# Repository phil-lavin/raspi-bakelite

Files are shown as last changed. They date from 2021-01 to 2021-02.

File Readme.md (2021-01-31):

Raspberry Pi Bakelite Phone VoIP Interface Board
================================================

Intro
-----

This repo contains the various bits of code that go to make up the VoIP conversion of a 1950s Bakelite phone using a Raspberry Pi.

The interface between the Raspberry Pi and the phone has been done by means of a custom designed [Pi Hat](https://github.com/raspberrypi/hats). 

Component Directories
---------------------

Below is a list of the components of this project. Each has its own Readme.md.

* eeprom: Contains all of the code held on the hat's 64Kbit EEPROM chip
* hat: Contains schematics, board designs and Gerber files for the custom designed Pi Hat
* ringer: Contains details of the original ringer bell of the Bakelite phone and how it's powered in the VoIP conversion

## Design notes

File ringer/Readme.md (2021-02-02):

Ringer
======

The Bakelite phone contains a pretty distinctive sounding ringer. It was important for this project
to preserve that sound. The ringer comprises of two solenoid coils, connected to a hammer. The AC
current causes the hammer to move back and forth between the coils, banging on the bells.

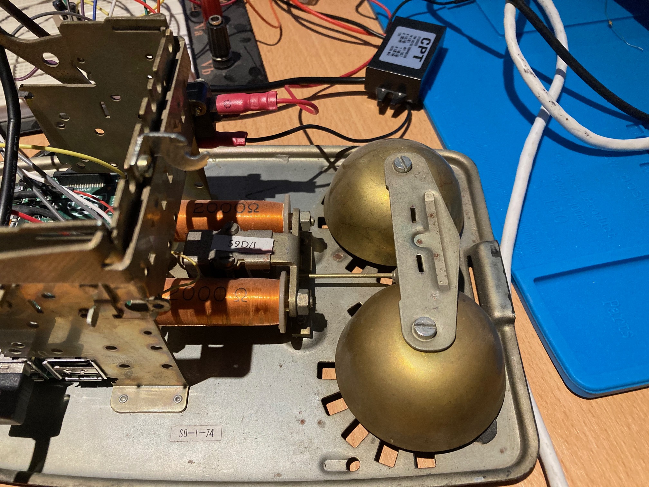
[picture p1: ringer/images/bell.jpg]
Ringer Bell

*Ringer Bells*

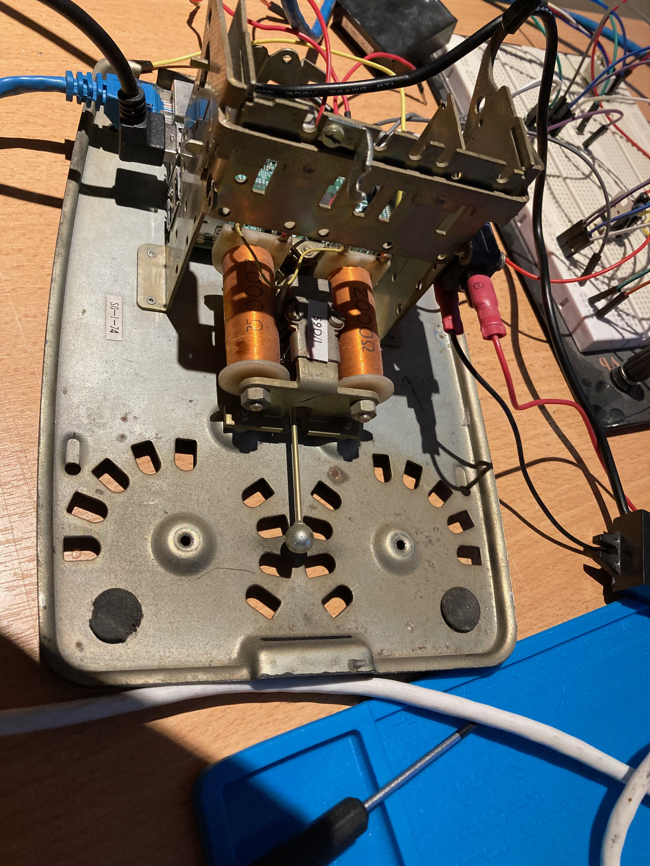
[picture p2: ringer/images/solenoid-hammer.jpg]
Solenoid Hammer

*Solenoid and Hammer with Bells Removed*

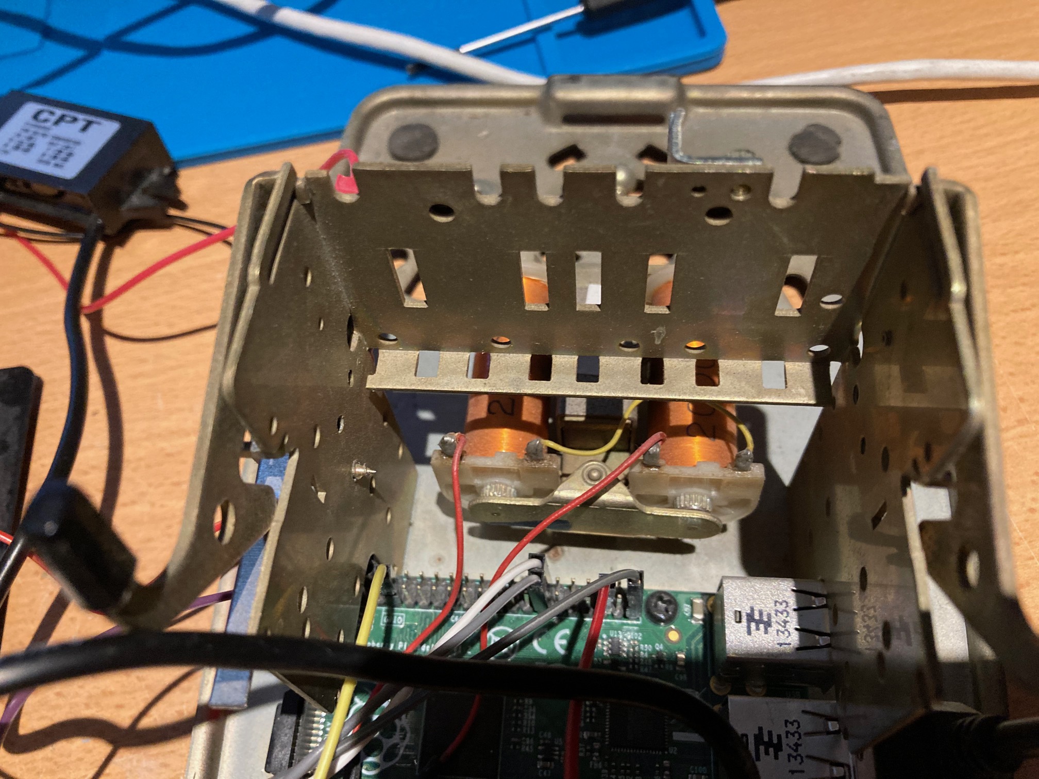
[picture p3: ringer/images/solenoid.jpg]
Solenoid

*Solenoid*

## Making it Ring

British PSTN ringing voltage is circa 75V AC at 25Hz. I decided to use the `PCR-SIN03V12F20-C` ring generator. 
This is a pre-packaged generator that converts 12V DC to 70V AC at 20Hz. Not exactly right, but who's going 
to notice?

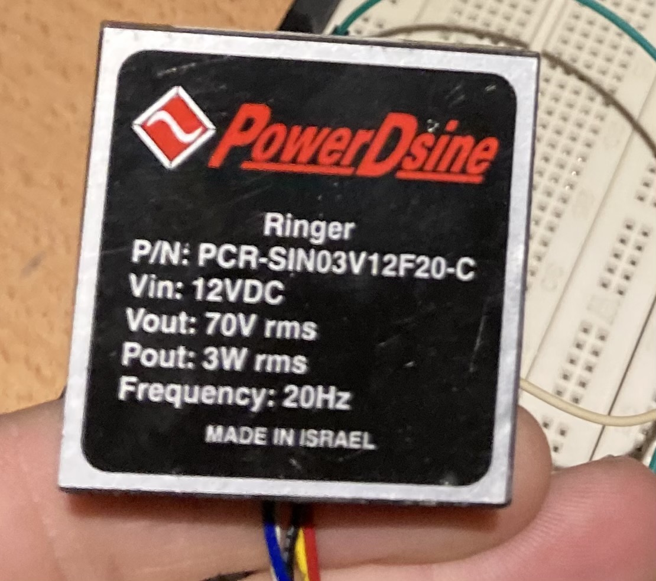
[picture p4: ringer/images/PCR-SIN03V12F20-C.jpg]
PCR-SIN03V12F20-C Ring Generator

*PCR-SIN03V12F20-C Ring Generator*

The `PCR-SIN03V12F20-C` has 6 pins (only 5 are connected):

* Pin 1: Connection to Solenoid
* Pin 2: Connection to Solenoid
* Pin 3: 12V DC
* Pin 4: GND
* Pin 5: 
* Pin 6: Inhibit

All pins should be pretty self explanatory, except Inhibit. When 5V (relative to GND) is applied to this pin 
it puts the device into low power mode and stops it outputting current to the solenoid.

When connected up to a scope, this is what the wave looks like:

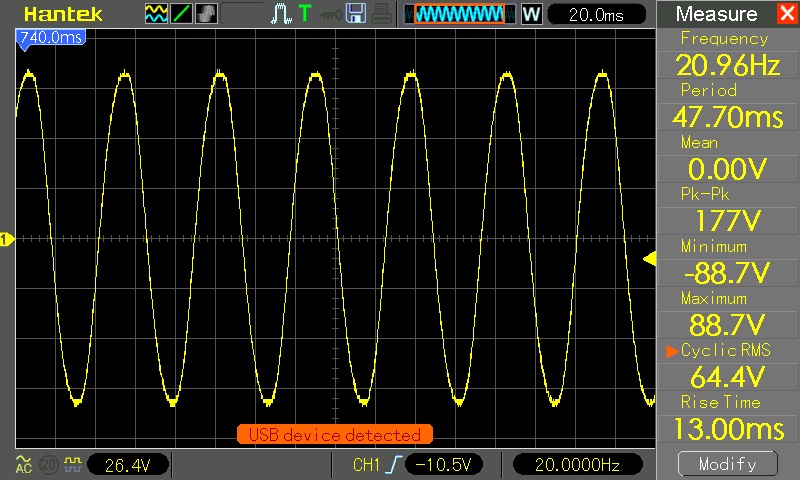
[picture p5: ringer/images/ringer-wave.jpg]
PCR-SIN03V12F20-C Wave


You can see that the wave is around 63V RMS at 20Hz. When connected to the solenoid, it makes a fantastic 
original sound.

## Circuit

The circuit to control the `PCR-SIN03V12F20-C` is pretty simple:

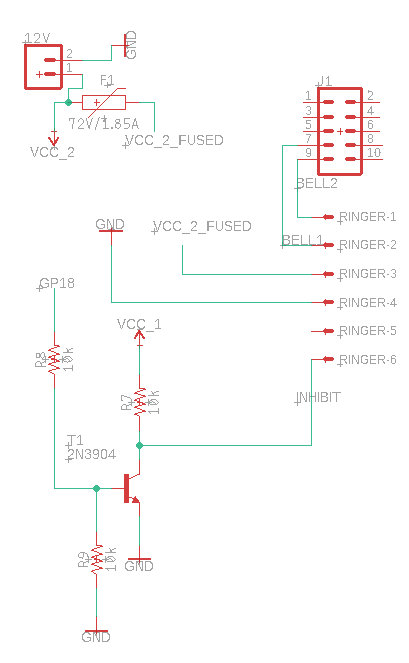
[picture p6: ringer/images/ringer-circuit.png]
PCR-SIN03V12F20-C Control Circuit


The `PCR-SIN03V12F20-C` ringer module takes a 12V power and GND input (pins 3 and 4) and it outputs to the Bakelite's original ringer (pins 1 and 2). Pin 6 of the ringer module is the `INHIBIT` pin. This 
pin takes a 5V logic input and when it's held high, the ringer stops outputting. When the pin is held low, the ringer outputs (and thus the bell rings). Because the Pi 
doesn't have any 5V GPIOs, this is fed via a transistor and simple inverter circuit. Under normal operation, the pin is tied directly to the 5V line via a 10K resistor. 
When the Pi's GPIO output goes high, this "opens up" the transistor and pulls the `INHIBIT` pin to GND. This makes the bell ring.

In essence, when the Pi's GPIO is high, the bell rings. When it's low, it doesn't.

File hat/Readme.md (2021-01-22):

Raspberry Pi Bakelite Phone VoIP Interface Board - Hat Designs
=========================================================

## Intro

The Bakelite Interface Board is designed to the functional and [mechanical specifications](https://github.com/raspberrypi/hats/blob/master/hat-board-mechanical.pdf) of a [Pi Hats](https://github.com/raspberrypi/hats).

This directory contains the Eagle cam files (schematic, board and gerbers... and image exports thereof) for the board.

## Schematic

Here is the Eagle schematic for the hat:

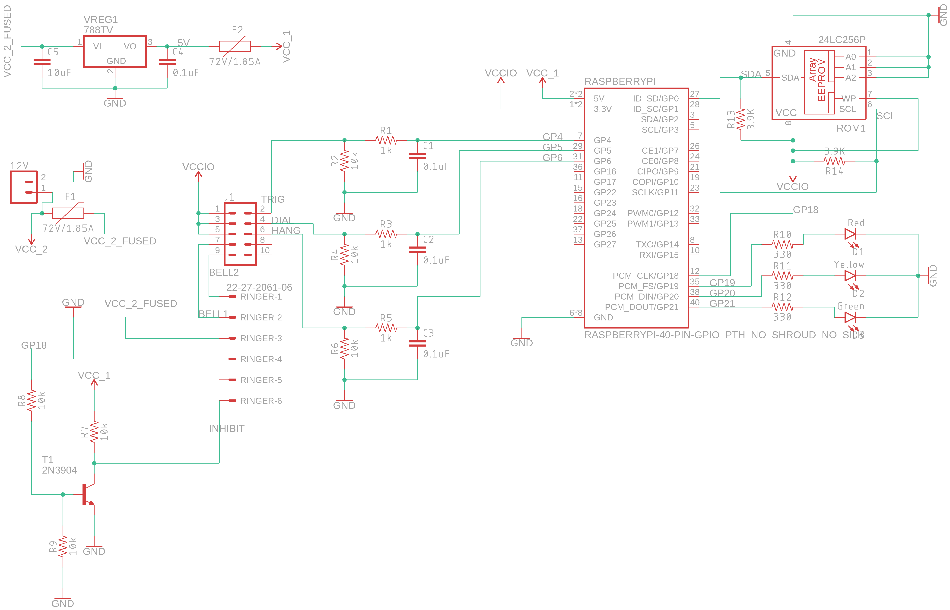
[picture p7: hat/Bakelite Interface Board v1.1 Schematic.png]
Eagle Schematic


The actual Eagle schematic file is also in this directory (the `.sch` file).

The schematic is focussed around the Raspberry Pi's 40 pin connector. This is just a 40 pin female connector, correctly positioned, on the Hat board such that 
the Hat sits directly on top of the Pi.

The schematic looks complicated but it's actually just a bunch of simple circuits all stitched together. These are:

### 12v Input (Middle Left of Schematic)

This is just a 2 pin screw header which takes an external 12V input (`VCC_2`) and puts it through a 2A resettable Polyfuse to create `VCC_2_FUSED`.

### 5v Power (Top Left of Schematic)

This takes the fused 12V output (`VCC_2_FUSED`) and passes it through a 5V regulator and a 2A resettable Polyfuse. This is then fed into the 5V pin of the Pi, 
thus providing power to the Pi from the 12V input.

The schematic notes that the regulator is a `788TV` (5V/2A Linear Regulator) but I will actually use the `K7805-2000` which is a pin compatible switching regulator.
It's more expensive but it's more efficient and runs a lot less hot, such that it doesn't need a heatsink.

The capacitors are just to ensure a smooth power feed is received.

### Ringer Control (Bottom Left of Schematic)

I am using a pre-packaged ring generator which is external from the board. This is a PowerDsine `PCR-SIN03V12F20-C`. It has a 6 pin Molex `2502` connector. This connector 
connects to the 6 pin connector on the board (labelled `RINGER-1` to `RINGER-6`).

The board also has a standard 10 pin header on it. The Bakelite's original ringer connects to this (pins 7 and 9).

The `PCR-SIN03V12F20-C` ringer module takes a 12V power and GND input (pins 3 and 4) and it outputs to the Bakelite's original ringer (pins 1 and 2). Pin 6 of the ringer module is the `INHIBIT` pin. This 
pin takes a 5V logic input and when it's held high, the ringer stops outputting. When the pin is held low, the ringer outputs (and thus the bell rings). Because the Pi 
doesn't have any 5V GPIOs, this is fed via a transistor and simple inverter circuit. Under normal operation, the pin is tied directly to the 5V line via a 10K resistor. 
When the Pi's GPIO output goes high, this "opens up" the transistor and pulls the `INHIBIT` pin to GND. This makes the bell ring.

In essence, when the Pi's GPIO is high, the bell rings. When it's low, it doesn't.

### "Switch" Inputs (Centre of Schematic)

The Bakelite phone has 3 switch-like inputs which we are interested in. All of these start in the on state. 

Two of the switch-like inputs are from the rotary dialler. One of them (named `TRIG` in the schematic) turns off when you start dialling and it turns back on when you stop dialling.
The next (named `DIAL`) in the schematic turns off and on again based on the number you dialled. This generates pulses - so if you dialled 5, you'd get 5 pulses.

The other switch-like input is not part of the original phone. Rather, it is a Long Lever Microswitch which has been attached to the phone just below the cradle that holds the handset.
When the handset is down, this switch is pressed (i.e. on). When the handset is lifted up, the switch turns off. This is connected to the `HANG` input on the schematic.

Each of these switches are connected to a GPIO pin on the Pi through a simple pulldown circuit with an added capacitor for debouncing the switch input. The GPIO pins are normally pulled 
to GND, until the switch is turned on when they are pulled to 3.3V.

### EEPROM Circuit (Top Right of Schematic)

It is a requirement of [Pi Hats](https://github.com/raspberrypi/hats) to have an EEPROM chip at least 32Kb in size connected to the ID (`ID_SC` and `ID_SD`) pins of the Pi.

The EEPROM chip should contain a number of components, in a [defined format](https://github.com/raspberrypi/hats/blob/master/eeprom-format.md), which describe the Hat, its GPIO usage and its Linux device tree. You can also include custom data.

This is much better documented in the eeprom folder of this repository.

### LEDs (Bottom Right of Schematic)

The board contains 3 LEDs, each connected via a resistor, to the Pi's GPIO pins. These can be used by the userland code to provide some sort of status and diagnostic output.

## Gerbers

The Gerber CAM files which have been built to the Design Rules of [Elecrow](https://www.elecrow.com/pcb-manufacturing.html) are in the gerbers directory.

There is a very small cutout at the edge of the board above pin 6 of the GPIO connector. This is just because of the way the Pi is positioned in the Bakelite phone, the Hat needs 
some provision for a bit of metalwork which exists in that space.

This is what a rendering of the top and bottom of the board looks like:

### Top

Top of Board

### Bottom

Bottom of Board

## Board

Here is the Eagle board for the hat:

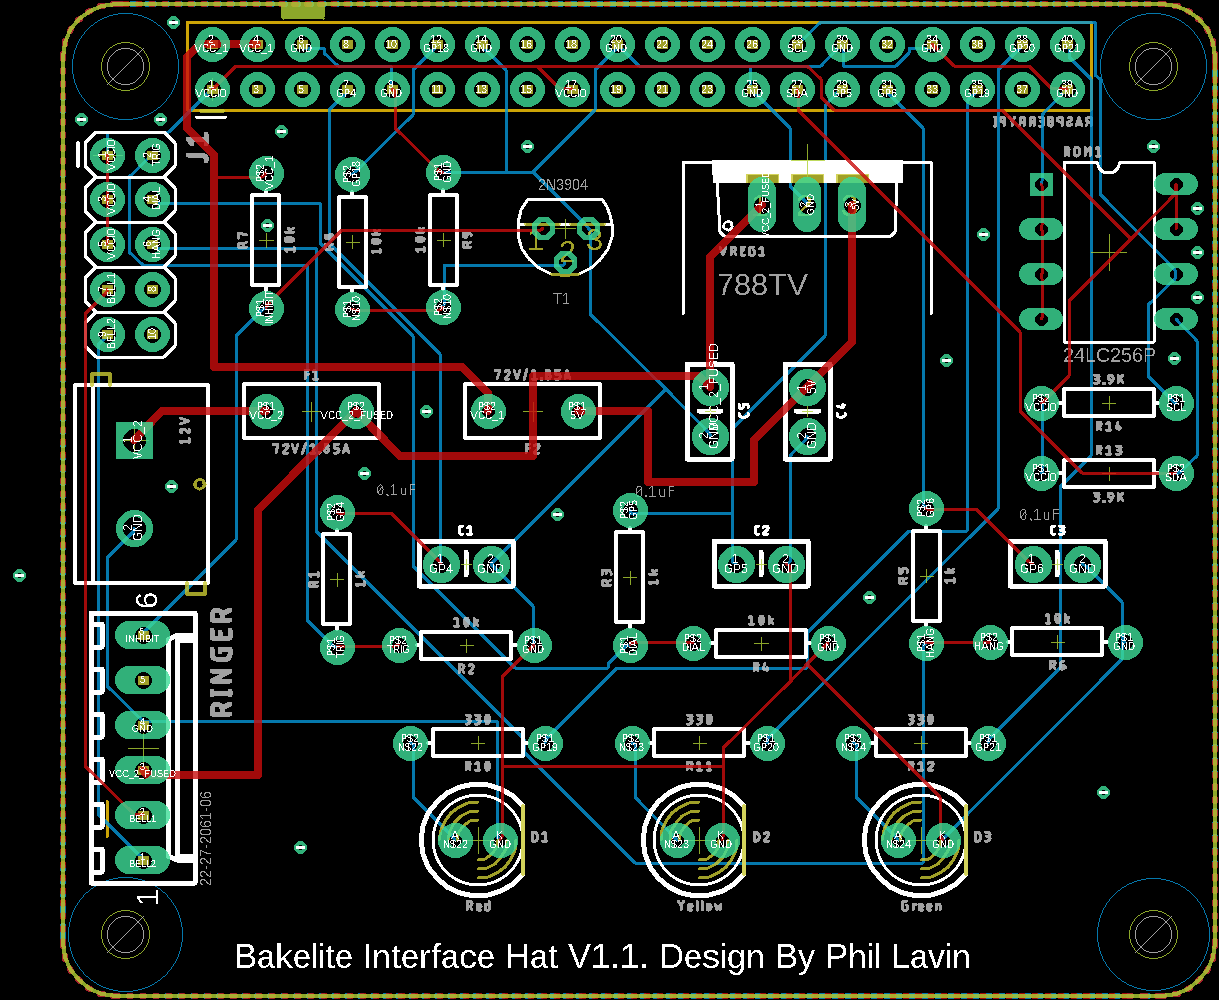
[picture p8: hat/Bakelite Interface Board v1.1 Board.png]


The actual Eagle board file is also in this directory (the `.brd` file).

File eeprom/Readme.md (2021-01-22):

Raspberry Pi Bakelite Phone VoIP Interface Board - EEPROM
=========================================================

## Intro

It is a requirement of [Pi Hats](https://github.com/raspberrypi/hats) to have an EEPROM chip at least 32Kb in size connected to the ID (`ID_SC` and `ID_SD`) pins of the Pi.

The EEPROM chip should contain a number of components, in a [defined format](https://github.com/raspberrypi/hats/blob/master/eeprom-format.md), which describe the Hat, its GPIO usage and its Linux device tree. You can also include custom data.

## Schematic

The EEPROM chip has a few pins:

* SDA/SCL: These are the I2C data lines - they connect to the matching pins on the Pi. They also need to be pulled up, via 3.9k resistors, to the 3.3V VCC
* VCC: 3.3V power input
* GND: Ground connection
* A0, A1, A2: These are the pins to set the I2C address of the EEPROM. They make up a 3 bit address, giving 8 possible addresses. Tying all 3 pins to GND makes the address 0x50, which is what the Pi Hat specification requires
* WP: This is the Write Protect pin. It should be tied to 3.3V if you want to prevent writing to the EEPROM. For the purpose of testing/programming the EEPROM, tie this to GND or leave it floating

Here is the Eagle schematic for this part of the Hat. VCCIO is the 3.3V line from the Pi.

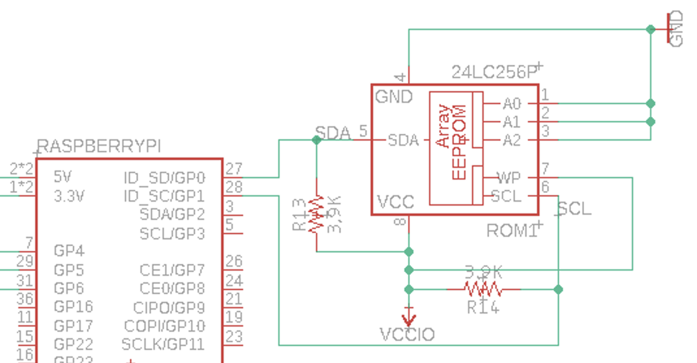
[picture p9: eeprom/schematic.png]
EEPROM Schematic
 

## Files

Below is a list of the files in this directory and a description of them:

* custom.txt: The custom data that gets flashed to the end of the EEPROM. This can be read, with some effort, by your applications
* dtc: Latest (at time of writing) version of the [Device Tree Compiler Toolchain](https://github.com/dgibson/dtc) as the version shipped on the Pi is buggy and segfaults when examining the Pi. This was compiled on a Pi Model B+ running Buster
* eeprom.py: A small bit of Python example code, demonstrating traversing the EEPROM's structure and pulling out the custom data written to the end of it
* eeprom_settings.txt: Settings file which is used to construct the main parts of the EEPROM's data
* flasheep.sh: Wrapper script around other tools to flash the EEPROM
* hats/: Git submodule of [Pi Hats](https://github.com/raspberrypi/hats) which contains the tools to build and flash the EEPROM data
* raspi-bakelite.dts: Device Tree definition file for the hat (described in much more depth below!)
* schematic.png: The schematic of the circuit which connects the EEPROM to the Pi

## Flashing the EEPROM

The EEPROM running on this Hat is a `24LC64` 64Kbit chip. The Pi Model B+ has 2 I2C busses, numbered 0 and 1. Bus 0 is the ID pins (27 and 28) and bus 1 is the `SDA`/`SCL` pins (3 and 5).

The Hat specification states that the I2C address of the EEPROM must be 0x50.

The process of flashing the EEPROM is:

* Compile the raspi-bakelie.dts file using dtc
* Build the EEPROM data image from the settings file, device tree and custom data files
* Flatten the EEPROM by writing 32Kbit of 0s to it (to save time as the actual EEPROM data is < 32Kbit)
* Write the data image we built to the chip

Flashing is done using the flasheep.sh wrapper script:

```
root@roto-voip:~/raspi-bakelite/eeprom# ./flasheep.sh 
raspi-bakelite.dts:63.24-67.19: Warning (unit_address_vs_reg): /fragment@2/__overlay__/trig/trig@4: node has a unit name, but no reg or ranges property
raspi-bakelite.dts:77.24-81.19: Warning (unit_address_vs_reg): /fragment@2/__overlay__/dial/dial@5: node has a unit name, but no reg or ranges property
raspi-bakelite.dts:91.24-95.19: Warning (unit_address_vs_reg): /fragment@2/__overlay__/hang/hang@6: node has a unit name, but no reg or ranges property
raspi-bakelite.dts:55.24-68.15: Warning (avoid_unnecessary_addr_size): /fragment@2/__overlay__/trig: unnecessary #address-cells/#size-cells without "ranges" or child "reg" property
raspi-bakelite.dts:69.24-82.15: Warning (avoid_unnecessary_addr_size): /fragment@2/__overlay__/dial: unnecessary #address-cells/#size-cells without "ranges" or child "reg" property
raspi-bakelite.dts:83.24-96.15: Warning (avoid_unnecessary_addr_size): /fragment@2/__overlay__/hang: unnecessary #address-cells/#size-cells without "ranges" or child "reg" property
Opening file eeprom_settings.txt for read
Done reading
Opening DT file raspi-bakelite.dtb for read
Adding 2819 bytes of DT data
Opening custom data file custom.txt for read
Adding 53 bytes of custom data
Writing out...
Writing out DT...
Done.
This will attempt to talk to an eeprom at i2c address 0x50 on bus 0. Make sure there is an eeprom at this address.
This script comes with ABSOLUTELY no warranty. Continue only if you know what you are doing.
Writing...
4096 bytes (4.1 kB, 4.0 KiB) copied, 22 s, 0.2 kB/s
8+0 records in
8+0 records out
4096 bytes (4.1 kB, 4.0 KiB) copied, 22.4986 s, 0.2 kB/s
Closing EEPROM Device.
Done.
This will attempt to talk to an eeprom at i2c address 0x50 on bus 0. Make sure there is an eeprom at this address.
This script comes with ABSOLUTELY no warranty. Continue only if you know what you are doing.
Writing...
2560 bytes (2.6 kB, 2.5 KiB) copied, 14 s, 0.2 kB/s
5+1 records in
5+1 records out
3010 bytes (3.0 kB, 2.9 KiB) copied, 16.5093 s, 0.2 kB/s
Closing EEPROM Device.
Done.
```

## EEPROM Settings

The eeprom_settings.txt file is pretty self explanatory, if you look at it. It defines the name and vendor of the board, that the board provides at least 2A of power to the Pi and it sets ip the 7 GPIO pins used by the Pi.

The custom data in this settings file appears to be limited to 3 bytes. Instead, you should use the custom.txt file to add custom data to the EEPROM which is only limited by the size of the ROM.

You can ensure the GPIO settings have applied with `raspi-gpio get`:

```
root@roto-voip:~/raspi-bakelite# raspi-gpio get | grep 'GPIO [456]:\|GPIO 1[89]\|GPIO 2[01]'
GPIO 4: level=0 fsel=0 func=INPUT
GPIO 5: level=0 fsel=0 func=INPUT
GPIO 6: level=0 fsel=0 func=INPUT
GPIO 18: level=0 fsel=1 func=OUTPUT
GPIO 19: level=0 fsel=1 func=OUTPUT
GPIO 20: level=0 fsel=1 func=OUTPUT
GPIO 21: level=1 fsel=1 func=OUTPUT
```

## EEPROM Custom Data

The custom data can be read off the EEPROM, with some effort, by understanding the [defined format](https://github.com/raspberrypi/hats/blob/master/eeprom-format.md) of the data.

The eeprom.py script in this directory gives a basic example of traversing the data and printing out any Atoms of type 0x0004 (manufacturer custom data).

```
root@roto-voip:~/raspi-bakelite/eeprom# python eeprom.py 
We have 4 atoms
Analysing atom 0
Type is 1
Length is 58
New offset is 78
Analysing atom 1
Type is 2
Length is 32
New offset is 118
Analysing atom 2
Type is 3
Length is 2821
New offset is 2947
Analysing atom 3
Type is 4
Length is 55
Custom data at atom 3: trig=4;dial=5;hang=6;ring=18;led1=19;led2=20;led3=21
```

## Device Tree

This is where things get complicated, and very poorly documented :/

A few useful references:

* https://mjoldfield.com/atelier/2017/03/rpi-devicetree.html
* https://developer.aliyun.com/mirror/npm/package/gpio-button/v/0.1.0
* https://github.com/torvalds/linux/blob/v4.19/include/uapi/linux/input-event-codes.h#L341
* https://www.kernel.org/doc/Documentation/devicetree/bindings/input/gpio-keys.txt
* https://learn.sparkfun.com/tutorials/reading-and-writing-serial-eeproms/all
* https://www.raspberrypi.org/documentation/configuration/device-tree.md

The raspi-bakelite.dts file defines the changes to the Linux Device Tree that should be made when the Pi boots.

It defines a few things:

### 3x LEDs

This maps the GPIO pins used by the LEDs on the Hat to /sys/class/leds/. This is useful because the userland code can now address named LEDs without having to know the pin numbers.

Turning on/off the LEDs is a simple as writing 1 or 0 to the brightness file handle. E.g:

```
echo 1 > /sys/class/leds/green/brightness
```

This turns on the green LED.

### Ringer

### 3x "Button" Inputs

These are the 3 physical switch inputs from the phone (dialing triggered, dialling and hang up). These are mapped to devices in /dev/input/by-path/ and also key presses 
on what is, effectively, a keyboard. Again, this is useful because we can respond to these named events without knowing the pin numbers.

You can use the evtest Linux tool to monitor the devices and report updates:

```
root@roto-voip:~/raspi-bakelite# evtest /dev/input/by-path/platform-soc\:trig-event 
Input driver version is 1.0.1
Input device ID: bus 0x19 vendor 0x1 product 0x1 version 0x100
Input device name: "soc:trig"
Supported events:
  Event type 0 (EV_SYN)
  Event type 1 (EV_KEY)
    Event code 260 (BTN_4)
Properties:
Testing ... (interrupt to exit)
Event: time 1611266120.098545, type 1 (EV_KEY), code 260 (BTN_4), value 1
Event: time 1611266120.098545, -------------- SYN_REPORT ------------
Event: time 1611266121.438556, type 1 (EV_KEY), code 260 (BTN_4), value 0
Event: time 1611266121.438556, -------------- SYN_REPORT ------------
```

### Ringer Output

This is a GPIO output which, via a transistor and basic 5v inverter, drives the INHIBIT pin on the ring generator. When this pin is HIGH, the phone rings, when it is LOW the phone stops 

The ringer output pin is mapped as an LED. There doesn't seem to be a more sensible output driver in Linux, so this'll have to do. It doesn't really matter - we only need a way to
turn it on and off on demand.

```
echo 1 > /sys/class/leds/ringer/brightness
```

This turns the ringer on.

## Testing

You can see the device tree and hat config as it has been translated to the file system with a few different commands:

```
root@roto-voip:~# ls /sys/class/leds/
green  led0  led1  orange  red	ringer

root@roto-voip:~/raspi-bakelite/eeprom# ls /dev/input/by-path/
platform-20980000.usb-usb-0:1.2:1.3-event  platform-soc:dial-event  platform-soc:hang-event  platform-soc:trig-event

root@roto-voip:~/raspi-bakelite/eeprom# grep -a '' /proc/device-tree/hat/*
/proc/device-tree/hat/custom_0:trig=4;dial=5;hang=6;ring=18;led1=19;led2=20;led3=21
/proc/device-tree/hat/name:hat
/proc/device-tree/hat/product:Bakelite Interface Board
/proc/device-tree/hat/product_id:0x0001
/proc/device-tree/hat/product_ver:0x0002
/proc/device-tree/hat/uuid:79f507e0-5b6f-11eb-ae93-0242ac130002
/proc/device-tree/hat/vendor:Phil Lavin

root@roto-voip:~/raspi-bakelite# raspi-gpio get
BANK0 (GPIO 0 to 27):
GPIO 0: level=1 fsel=4 alt=0 func=SDA0
GPIO 1: level=1 fsel=4 alt=0 func=SCL0
GPIO 2: level=1 fsel=4 alt=0 func=SDA1
GPIO 3: level=1 fsel=4 alt=0 func=SCL1
GPIO 4: level=0 fsel=0 func=INPUT
GPIO 5: level=0 fsel=0 func=INPUT
GPIO 6: level=0 fsel=0 func=INPUT
GPIO 7: level=1 fsel=0 func=INPUT
GPIO 8: level=1 fsel=0 func=INPUT
GPIO 9: level=0 fsel=0 func=INPUT
GPIO 10: level=0 fsel=0 func=INPUT
GPIO 11: level=0 fsel=0 func=INPUT
GPIO 12: level=0 fsel=0 func=INPUT
GPIO 13: level=0 fsel=0 func=INPUT
GPIO 14: level=1 fsel=4 alt=0 func=TXD0
GPIO 15: level=1 fsel=4 alt=0 func=RXD0
GPIO 16: level=0 fsel=0 func=INPUT
GPIO 17: level=0 fsel=0 func=INPUT
GPIO 18: level=0 fsel=1 func=OUTPUT
GPIO 19: level=0 fsel=1 func=OUTPUT
GPIO 20: level=0 fsel=1 func=OUTPUT
GPIO 21: level=0 fsel=1 func=OUTPUT
GPIO 22: level=0 fsel=0 func=INPUT
GPIO 23: level=0 fsel=0 func=INPUT
GPIO 24: level=0 fsel=0 func=INPUT
GPIO 25: level=0 fsel=0 func=INPUT
GPIO 26: level=0 fsel=0 func=INPUT
GPIO 27: level=1 fsel=0 func=INPUT
```

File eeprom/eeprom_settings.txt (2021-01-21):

########################################################################
# EEPROM settings text file
#
# Edit this file for your particular board and run through eepmake tool,
# then use eepflash tool to write to attached HAT ID EEPROM 
#
# Tools available:
#  eepmake   Parses EEPROM text file and creates binary .eep file
#  eepdump   Dumps a binary .eep file as human readable text (for debug)
#  eepflash  Write or read .eep binary image to/from HAT EEPROM
#
########################################################################

########################################################################
# Vendor info

# 128 bit UUID. If left at zero eepmake tool will auto-generate
# RFC 4122 compliant UUID
product_uuid 79f507e0-5b6f-11eb-ae93-0242ac130002

# 16 bit product id
product_id 0x0001

# 16 bit product version
product_ver 0x0002

# ASCII vendor string  (max 255 characters)
vendor "Phil Lavin"

# ASCII product string (max 255 characters)
product "Bakelite Interface Board"

# Custom binary data
#custom_data
#66756b
#end

########################################################################
# GPIO bank settings, set to nonzero to change from the default.
# NOTE these setting can only be set per BANK, uncommenting any of
# these will force the bank to use the custom setting.

# drive strength, 0=default, 1-8=2,4,6,8,10,12,14,16mA, 9-15=reserved
gpio_drive 0

# 0=default, 1=slew rate limiting, 2=no slew limiting, 3=reserved
gpio_slew 0

# 0=default, 1=hysteresis disabled, 2=hysteresis enabled, 3=reserved
gpio_hysteresis 0

# If board back-powers Pi via 5V GPIO header pins:
# 0 = board does not back-power
# 1 = board back-powers and can supply the Pi with a minimum of 1.3A
# 2 = board back-powers and can supply the Pi with a minimum of 2A
# 3 = reserved
# If back_power=2 then USB high current mode will be automatically 
# enabled on the Pi
back_power 2

########################################################################
# GPIO pins, uncomment for GPIOs used on board
# Options for FUNCTION: INPUT, OUTPUT, ALT0-ALT5
# Options for PULL: DEFAULT, UP, DOWN, NONE
# NB GPIO0 and GPIO1 are reserved for ID EEPROM so cannot be set

#         GPIO  FUNCTION  PULL
#         ----  --------  ----
#setgpio  2     INPUT     DEFAULT
#setgpio  3     INPUT     DEFAULT
setgpio  4     INPUT     DOWN
setgpio  5     INPUT     DOWN
setgpio  6     INPUT     DOWN
#setgpio  7     INPUT     DEFAULT
#setgpio  8     INPUT     DEFAULT
#setgpio  9     INPUT     DEFAULT
#setgpio  10    INPUT     DEFAULT
#setgpio  11    INPUT     DEFAULT
#setgpio  12    INPUT     DEFAULT
#setgpio  13    INPUT     DEFAULT
#setgpio  14    INPUT     DEFAULT
#setgpio  15    INPUT     DEFAULT
#setgpio  16    INPUT     DEFAULT
#setgpio  17    INPUT     DEFAULT
setgpio  18    OUTPUT     DOWN
setgpio  19    OUTPUT     DOWN
setgpio  20    OUTPUT     DOWN
setgpio  21    OUTPUT     DOWN
#setgpio  22    INPUT     DEFAULT
#setgpio  23    INPUT     DEFAULT
#setgpio  24    INPUT     DEFAULT
#setgpio  25    INPUT     DEFAULT
#setgpio  26    INPUT     DEFAULT
#setgpio  27    INPUT     DEFAULT

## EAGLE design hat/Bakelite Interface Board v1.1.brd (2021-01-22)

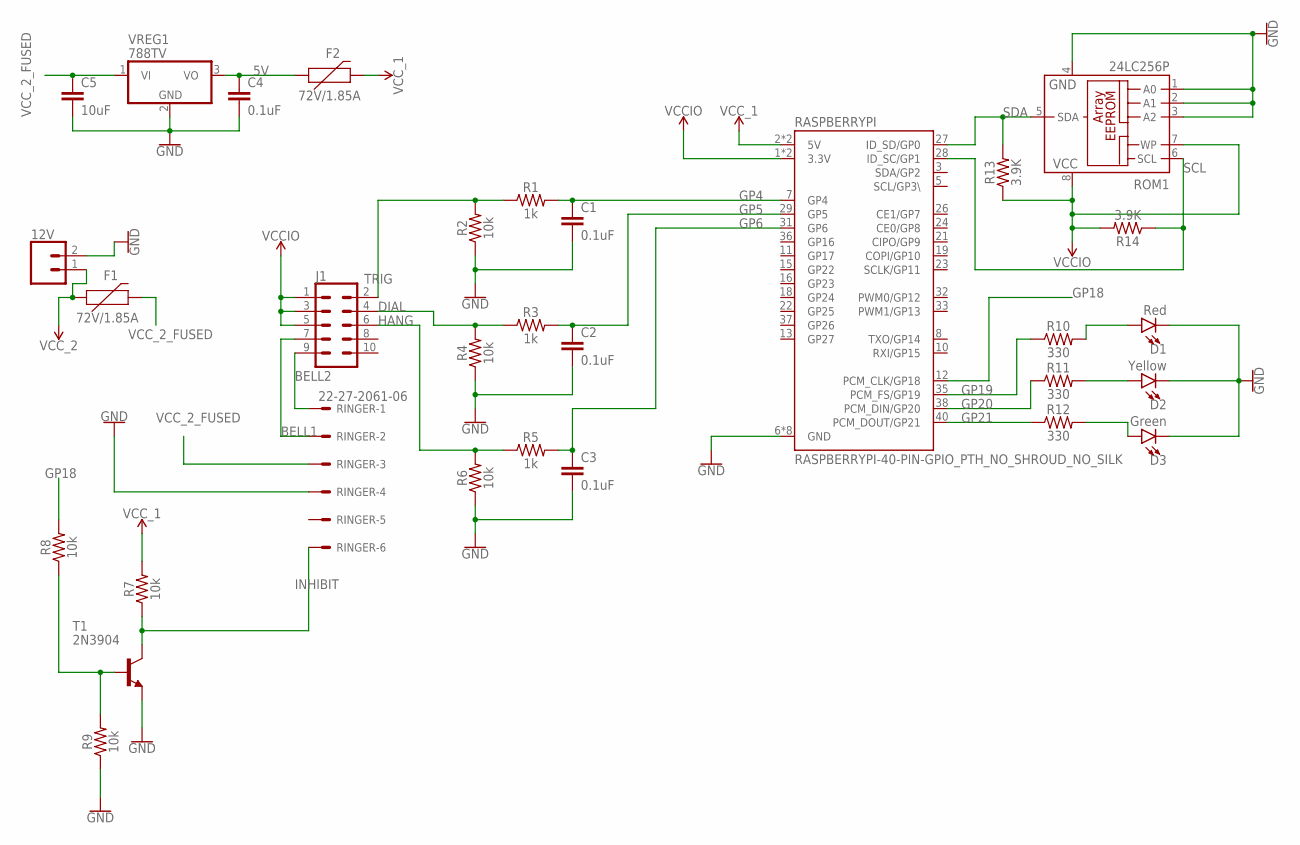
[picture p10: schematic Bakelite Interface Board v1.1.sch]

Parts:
12V: CONN_025MM; SCREWTERMINAL-5MM-2
C1, C2, C3, C4: 0.1uF; CAP-PTH-SMALL-KIT
C5: 10uF; CAP-PTH-SMALL-KIT
D1: Red; LED_5MM
D2: Yellow; LED_5MM
D3: Green; LED_5MM
F1, F2: 72V/1.85A; PTH
J1: CONN_05X2PTH; 2X5
R1, R3, R5: 1k; AXIAL-0.3
R2, R4, R6, R7, R8, R9: 10k; AXIAL-0.3
R10, R11, R12: 330; AXIAL-0.3
R13, R14: 3.9K; AXIAL-0.3
RASPBERRYPI: RASPBERRYPI-40-PIN-GPIO_PTH_NO_SHROUD_NO_SILK; 2X20_NOSILK
RINGER: 22-27-2061-06; 6410-06
ROM1: 24LC256P; DIL8
T1: 2N3904; TO92
VREG1: 788TV; TO220V

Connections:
5V: C4.1, F2.P$1 (1), VREG1.3 (VO)
BELL1: J1.7, RINGER.2
BELL2: J1.9, RINGER.1
DIAL: J1.4, R3.P$1 (1), R4.P$2 (2)
GND: 12V.2, C1.2, C2.2, C3.2, C4.2, C5.2, D1.K (C), D2.K (C), D3.K (C), R2.P$1 (1), R4.P$1 (1), R6.P$1 (1), R9.P$1 (1), RASPBERRYPI.6 (GND), RASPBERRYPI.9 (GND), RASPBERRYPI.14 (GND), RASPBERRYPI.20 (GND), RASPBERRYPI.25 (GND), RASPBERRYPI.30 (GND), RASPBERRYPI.34 (GND), RASPBERRYPI.39 (GND), RINGER.4, ROM1.1 (A0), ROM1.2 (A1), ROM1.3 (A2), ROM1.4 (GND), T1.3 (E), VREG1.2 (GND)
GP4: C1.1, R1.P$2 (2), RASPBERRYPI.7 (GP4)
GP5: C2.1, R3.P$2 (2), RASPBERRYPI.29 (GP5)
GP6: C3.1, R5.P$2 (2), RASPBERRYPI.31 (GP6)
GP18: R8.P$2 (2), RASPBERRYPI.12 (PCM_CLK/GP18)
GP19: R10.P$1 (1), RASPBERRYPI.35 (PCM_FS/GP19)
GP20: R11.P$1 (1), RASPBERRYPI.38 (PCM_DIN/GP20)
GP21: R12.P$1 (1), RASPBERRYPI.40 (PCM_DOUT/GP21)
HANG: J1.6, R5.P$1 (1), R6.P$2 (2)
INHIBIT: R7.P$1 (1), RINGER.6, T1.1 (C)
unnamed: R8.P$1 (1), R9.P$2 (2), T1.2 (B)
unnamed: D1.A, R10.P$2 (2)
unnamed: D2.A, R11.P$2 (2)
unnamed: D3.A, R12.P$2 (2)
SCL: R14.P$1 (1), RASPBERRYPI.28 (ID_SC/GP1), ROM1.6 (SCL)
SDA: R13.P$2 (2), RASPBERRYPI.27 (ID_SD/GP0), ROM1.5 (SDA)
TRIG: J1.2, R1.P$1 (1), R2.P$2 (2)
VCCIO: J1.1, J1.3, J1.5, R13.P$1 (1), R14.P$2 (2), RASPBERRYPI.1 (3.3V), RASPBERRYPI.17 (3.3V), ROM1.7 (WP), ROM1.8 (VCC)
VCC_1: F2.P$2 (2), R7.P$2 (2), RASPBERRYPI.2 (5V), RASPBERRYPI.4 (5V)
VCC_2: 12V.1, F1.P$1 (1)
VCC_2_FUSED: C5.1, F1.P$2 (2), RINGER.3, VREG1.1 (VI)

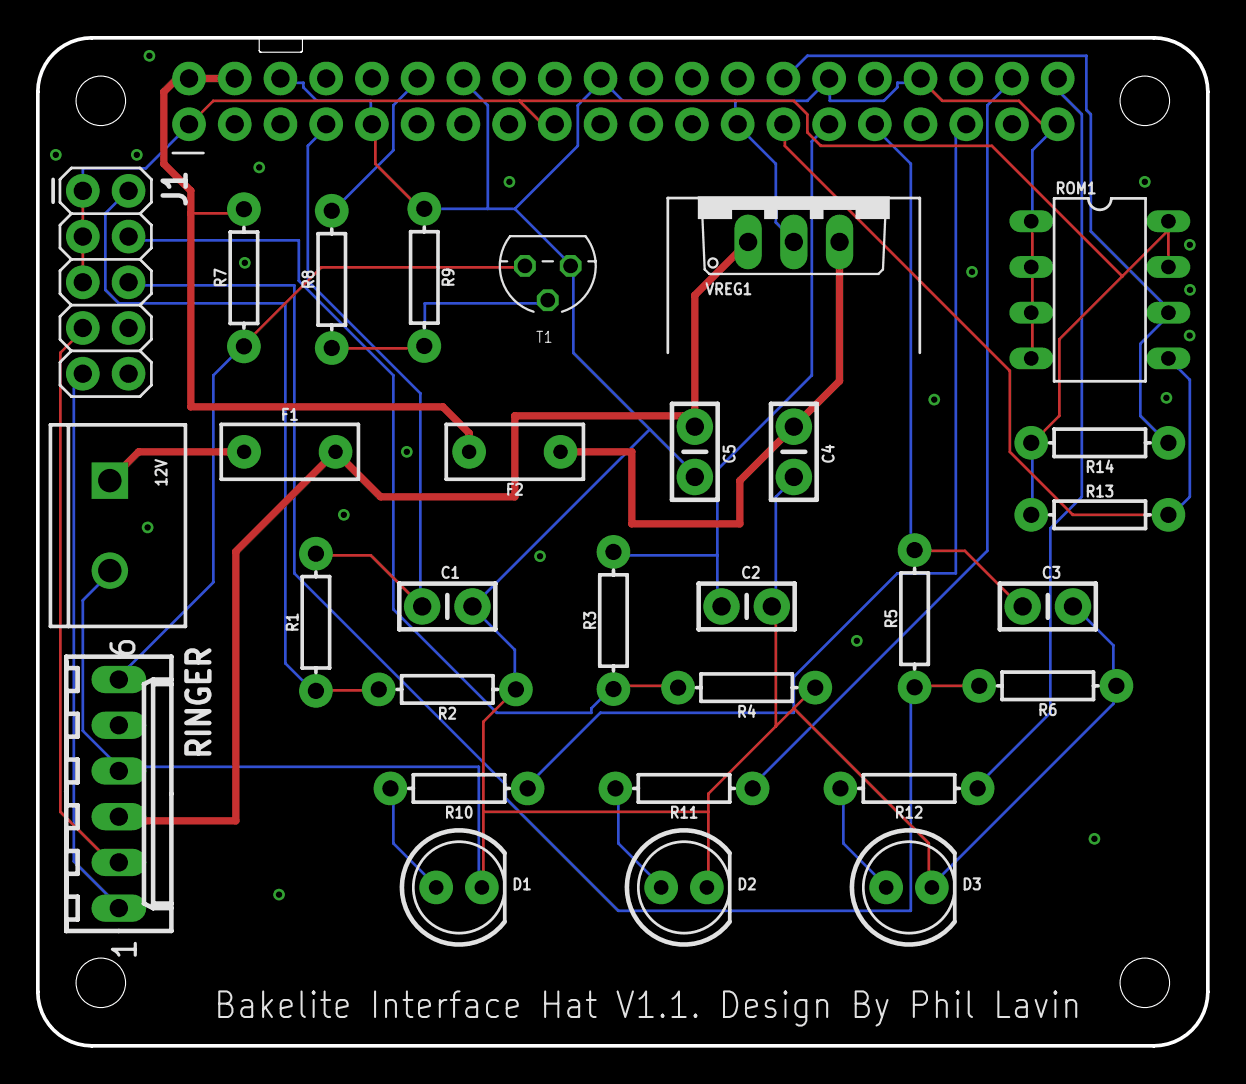
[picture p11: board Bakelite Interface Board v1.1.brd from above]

Board: 2 copper layers, 65.0 x 56.0 mm, 31 parts (0 on the bottom side), 25 nets.

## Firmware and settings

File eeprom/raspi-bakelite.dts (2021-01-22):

/dts-v1/;
/plugin/;

/{
    compatible = "brcm,bcm2835", "brcm,bcm2708", "brcm,bcm2709";

    // Set up our ringer and 3 on board LEDs. These will be created in /sys/class/leds
    // Ringer (obviously) isn't an LED but there doesn't seem to be a more sensible control driver in Linux
    fragment@0 {
        target = <&leds>;
        __overlay__ {
            output_ringer: ringer {
                label = "ringer";
                gpios = <&gpio 18 0>; /* gpio 18 */
                linux,default-trigger = "none";
            };
            led_red: red {
                label = "red";
                gpios = <&gpio 19 0>; /* gpio 19 */
                linux,default-trigger = "none";
            };
            led_orange: orange {
                label = "orange";
                gpios = <&gpio 20 0>; /* gpio 20 */
                linux,default-trigger = "none";
            };
            led_green: green {
                label = "green";
                gpios = <&gpio 21 0>; /* gpio 21 */
                linux,default-trigger = "none";
            };
        };
    };

    // Set up our trig, dial and hang inputs
    fragment@1 {
        target = <&gpio>;
        __overlay__ {
            trig_pin: trig_pin {
                brcm,pins = <4>;     /* gpio4 */
                brcm,function = <0>; /* input */
                brcm,pull = <1>;     /* pull-down */
            };
            dial_pin: dial_pin {
                brcm,pins = <5>;     /* gpio5 */
                brcm,function = <0>; /* input */
                brcm,pull = <1>;     /* pull-down */
            };
            hang_pin: hang_pin {
                brcm,pins = <6>;     /* gpio6 */
                brcm,function = <0>; /* input */
                brcm,pull = <1>;     /* pull-down */
            };
        };
    };

    // Map the trig, dial and hang buttons to key codes (https://github.com/torvalds/linux/blob/v4.19/include/uapi/linux/input-event-codes.h#L341)
    // This also adds them as devices in /dev/input/by-path/
    fragment@2 {
        target-path = "/soc";
        __overlay__ {
            trig: trig {
                compatible = "gpio-keys";
                #address-cells = <1>;
                #size-cells = <0>;
                pinctrl-names = "default";
                pinctrl-0 = <&trig_pin>;
                status = "okay";

                trig@4 {
                    label = "trig buton";
                    linux,code = <0x104>;
                    gpios = <&gpio 4 0>;
                };
            };
            dial: dial {
                compatible = "gpio-keys";
                #address-cells = <1>;
                #size-cells = <0>;
                pinctrl-names = "default";
                pinctrl-0 = <&dial_pin>;
                status = "okay";

                dial@5 {
                    label = "dial buton";
                    linux,code = <0x105>;
                    gpios = <&gpio 5 0>;
                };
            };
            hang: hang {
                compatible = "gpio-keys";
                #address-cells = <1>;
                #size-cells = <0>;
                pinctrl-names = "default";
                pinctrl-0 = <&hang_pin>;
                status = "okay";

                hang@6 {
                    label = "hang buton";
                    linux,code = <0x106>;
                    gpios = <&gpio 6 0>;
                };
            };
        };
    };
};

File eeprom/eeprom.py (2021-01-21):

#!/usr/bin/env python
import smbus
import time
import sys

# Config
bus = smbus.SMBus(0)   # I2C bus number
Dev_Addr = 0x50        # I2C device 7 bit address
debug = True           # Print debug info from this script

# Debug logger
def debug_log(s):
    if debug:
        print(s)

# Handle skipping to the correct part of the EEPROM
def skip(pos):
    # A 64Kb EEPROM has 8192 Bytes. We must break the 2 byte position (pos) into
    # the high and low bytes and pass them separately
    high = pos >> 8
    low = pos % 256

    bus.write_i2c_block_data(Dev_Addr, high, [low]) # Does the skipping

# Get number of atoms (2 byte, Little Endian)
skip(6) # Bytes 6 and 7 are the number of atoms
b1 = bus.read_byte(Dev_Addr)
b2 = bus.read_byte(Dev_Addr)
atoms = b2<<8 | b1
debug_log("We have " + str(atoms) + " atoms")

# Set our offset to the end of the header (i.e. start of first atom)
offset = 12

# Loop through each atom and get type and length
for i in range (0, atoms):
    debug_log("Analysing atom " + str(i))

    skip(offset) # Skip to start of this atom
    b1 = bus.read_byte(Dev_Addr)
    b2 = bus.read_byte(Dev_Addr)
    type = b2<<8 | b1
    debug_log("Type is " + str(type))

    skip(offset+4) # Skip to start of length
    b1 = bus.read_byte(Dev_Addr)
    b2 = bus.read_byte(Dev_Addr)
    len = b2<<8 | b1
    debug_log("Length is " + str(len)) # Length is of data+CRC. Total atom is 8 bytes bigger than this

    # Atom is type 4 (Manufacturer custom data)
    if type == 4:
        customData = ""
        skip(offset+8) # Skip to start of data

        # Read data (data length is len - 2 byte CRC)
        for j in range (0, len - 2):
            customData += chr(bus.read_byte(Dev_Addr))

        # Dump it
        print("Custom data at atom " + str(i) + ": " + customData)

    offset = offset + len + 8 # Set offset to start of next atom
    debug_log("New offset is " + str(offset))

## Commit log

2021-01-22 Add reference for Device Tree
2021-01-22 Add EEPROM schematic
2021-01-22 Tidy up EEPROM schematic
2021-01-22 EEPROM: Update LED configuration - refactor and add ringer
2021-01-22 Add Eagle files and images thereof
    [Bakelite Interface Board v1.1.GBL, Bakelite Interface Board v1.1.GBO, Bakelite Interface Board v1.1.GBP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]
2021-01-22 Hat: Title gerber renderings in readme
2021-01-22 Hat: Update Board image to include tValues and bValues layers
2021-01-22 Add schematic documentation to the hat README
2021-01-22 Hat: Document the 40 pin connector
2021-01-22 Hat README: Document the cutout above pin 6
2021-02-02 Add details of ringer circuit to ringer/ Readme
2021-04-23 Start of hardware devices support - Off Hook detection added
2021-04-24 Refactor timers to use a Timer Manager
2021-04-24 Add Maximum Runs support to timers
2021-04-24 Enable ringback on 180 response on outbound calls
    This was a real pain on Raspberry Pi as BareSIP tries to open the alsa device
    twice (once for ringback, once for actual audio).
    The "solution" is to use the alsa dmix plugin, as per: https://github.com/baresip/baresip/issues/832#issuecomment-547701825
    This commit also includes an example asound.conf for creating a dmix device from a USB sound card

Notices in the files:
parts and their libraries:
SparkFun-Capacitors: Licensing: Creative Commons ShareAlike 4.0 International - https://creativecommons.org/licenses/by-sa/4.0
